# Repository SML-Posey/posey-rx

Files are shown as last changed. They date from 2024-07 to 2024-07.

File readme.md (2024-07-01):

# Posey Ring Platform

This is a simple IMU hardware platform sized to fit in a ring unit.

It includes:

- nRF52832 ARM microtroller with BLE radio
- CEVA BNO086 9-axis IMU
- Lithium-polymer operation and charging

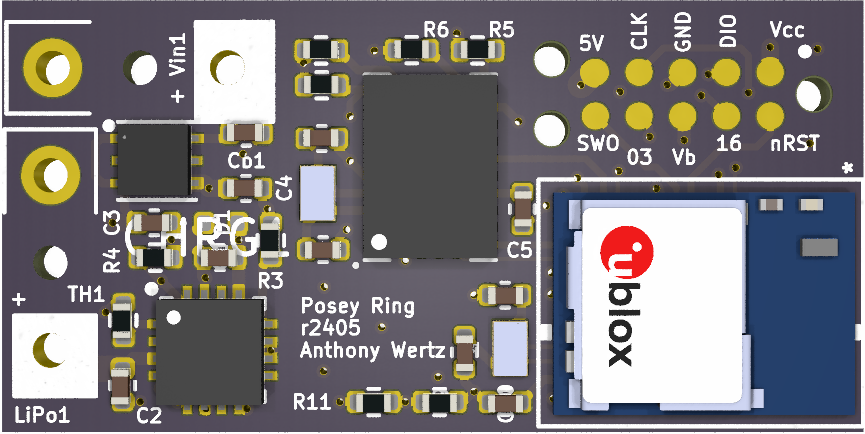
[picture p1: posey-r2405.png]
CAD rendering


## Author

[Anthony Wertz](https://me.anthonywertz.com)

## License

Shield: [][cc-by-sa]

This work is licensed under a
[Creative Commons Attribution-ShareAlike 4.0 International License][cc-by-sa].

[][cc-by-sa]

[cc-by-sa]: http://creativecommons.org/licenses/by-sa/4.0/
[cc-by-sa-image]: https://licensebuttons.net/l/by-sa/4.0/88x31.png
[cc-by-sa-shield]: https://img.shields.io/badge/License-CC%20BY--SA%204.0-lightgrey.svg

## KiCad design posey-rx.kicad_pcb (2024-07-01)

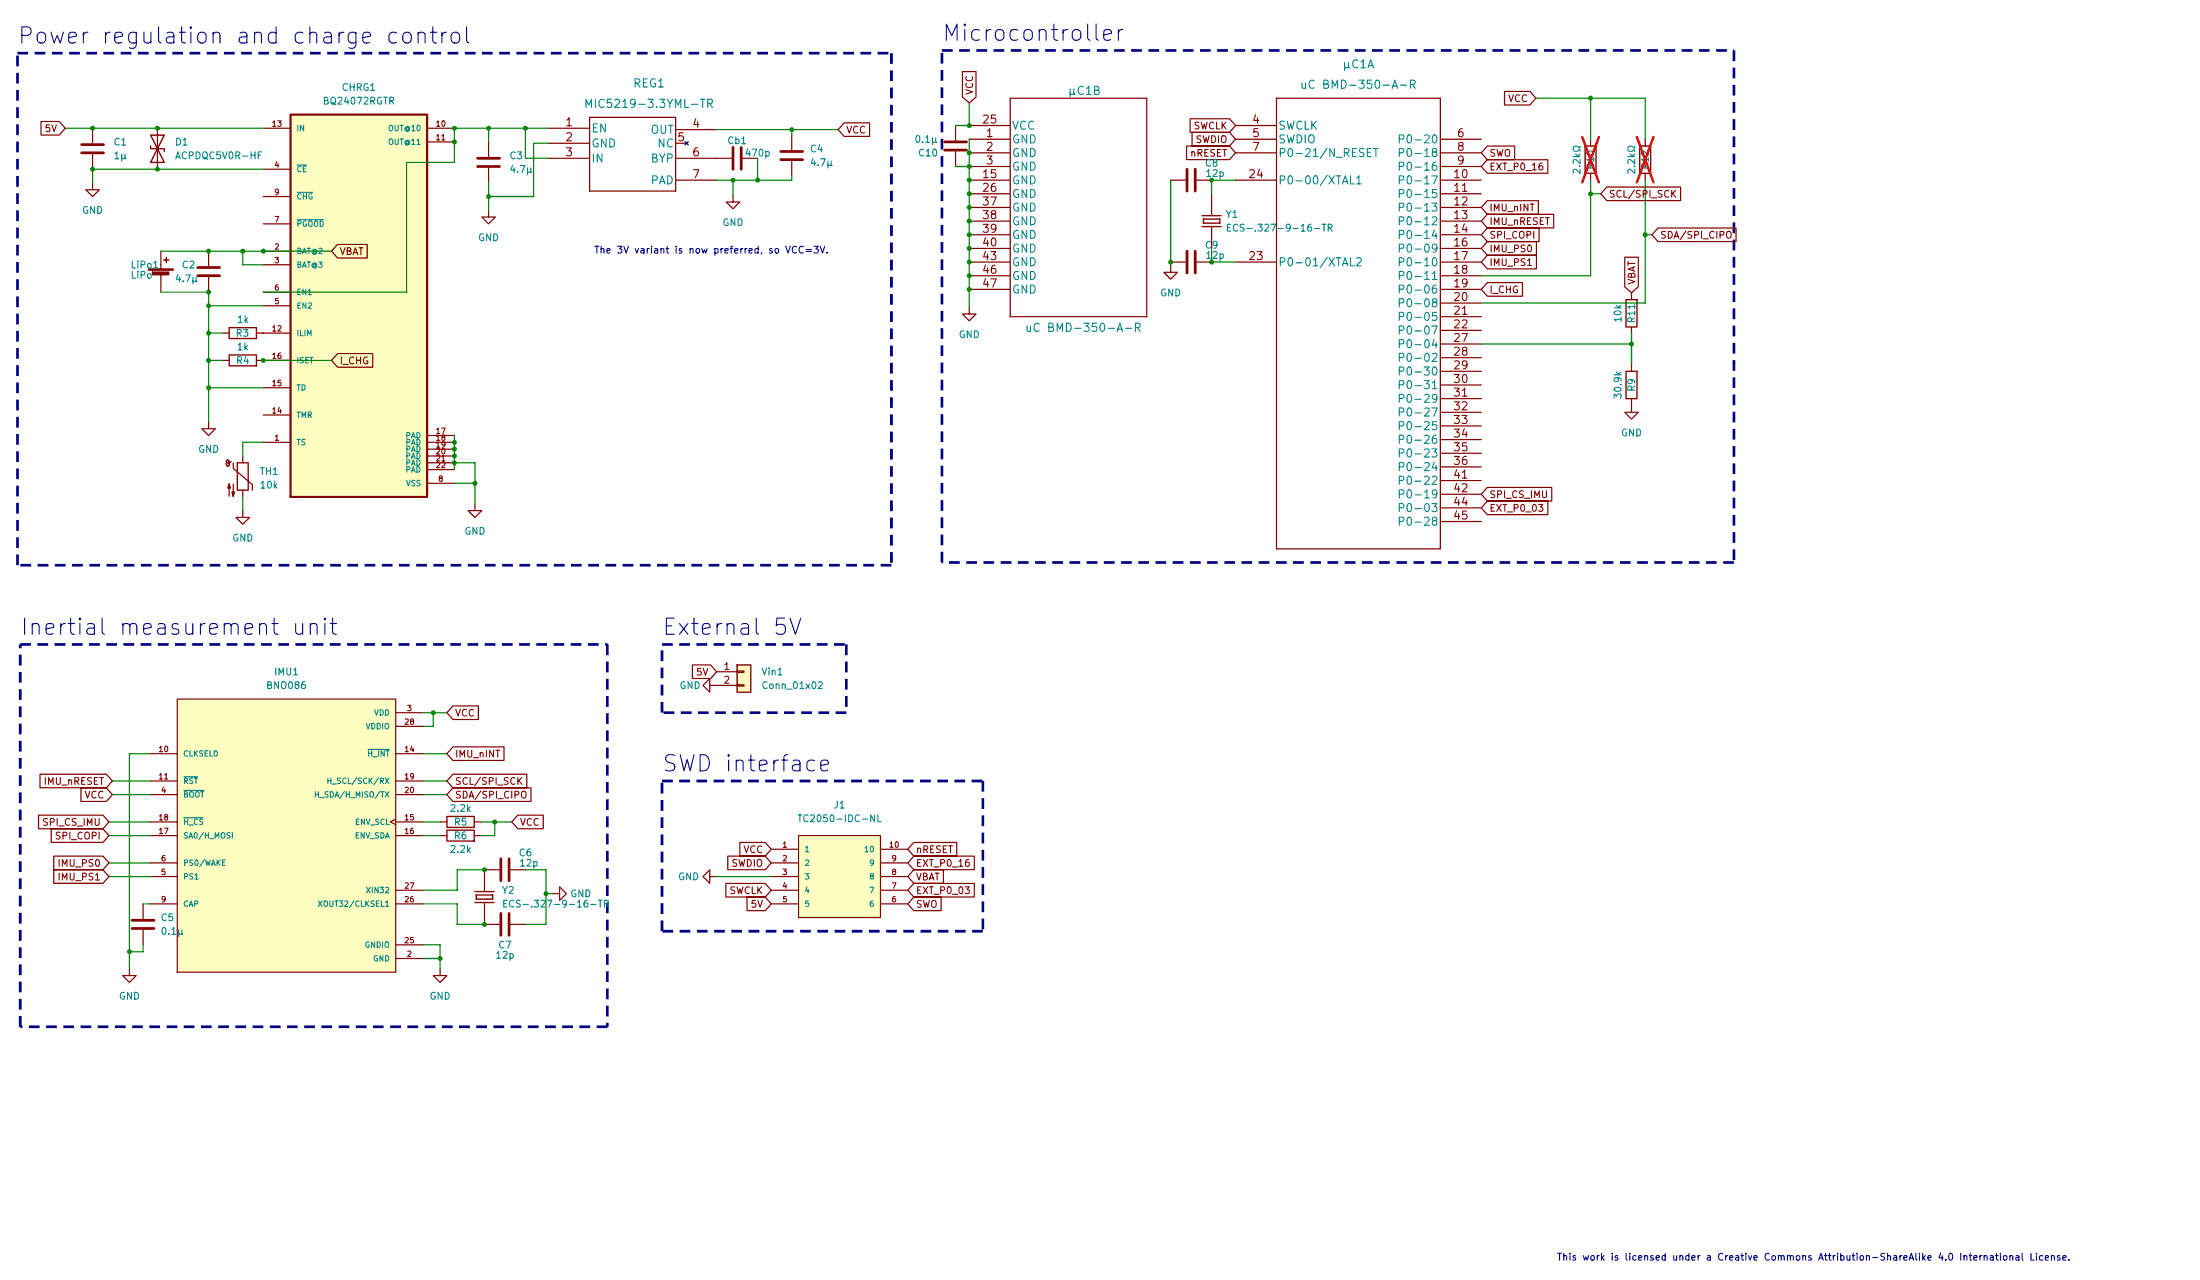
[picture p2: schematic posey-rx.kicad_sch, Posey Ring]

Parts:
C1: 1µ; C_0402_1005Metric
C2, C3, C4: 4.7µ; C_0402_1005Metric
C5, C10: 0.1µ; C_0402_1005Metric
C6, C7, C8, C9: 12p; C_0402_1005Metric
CHRG1: BQ24072RGTR; QFN50P300X300X100-17N
Cb1: 470p; C_0402_1005Metric
D1: ACPDQC5V0R-HF; D_0402_1005Metric
IMU1: BNO086; IC_BNO080
J1: TC2050-IDC-NL
LiPo1: LiPo; Split Terminal 2.54
R3, R4: 1k; R_0402_1005Metric
R5, R6: 2.2k; R_0402_1005Metric
R9: 30.9k; R_0402_1005Metric
R10, R12: 2.2kΩ; R_0402_1005Metric; not fitted
R11: 10k; R_0402_1005Metric
REG1: MIC5219-3.3YML-TR
TH1: 10k; R_0402_1005Metric
Vin1: Conn_01x02; Split Terminal 2.54
Y1, Y2: ECS-.327-9-16-TR; XTAL_ECS-.327-9-16-TR
µC1: uC BMD-350-A-R; BMD-350-A-R

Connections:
5V: C1.1, CHRG1.13 (IN), D1.2 (A2), J1.5, Vin1.1
EXT_P0_03: J1.7, µC1.44 (P0-03)
EXT_P0_16: J1.9, µC1.9 (P0-16)
GND: C1.2, C2.1, C3.2, C4.2, C5.2, C6.2, C7.2, C8.1, C9.1, C10.1, CHRG1.4 (~CE), CHRG1.5 (EN2), CHRG1.8 (VSS), CHRG1.15 (TD), CHRG1.17 (PAD), CHRG1.18 (PAD), CHRG1.19 (PAD), CHRG1.20 (PAD), CHRG1.21 (PAD), CHRG1.22 (PAD), Cb1.2, D1.1 (A1), IMU1.2 (GND), IMU1.10 (CLKSEL0), IMU1.25 (GNDIO), J1.3, LiPo1.2 (-), R3.1, R4.1, R9.1, REG1.2 (GND), REG1.7 (PAD), TH1.2, Vin1.2, µC1.1 (GND), µC1.2 (GND), µC1.3 (GND), µC1.15 (GND), µC1.26 (GND), µC1.37 (GND), µC1.38 (GND), µC1.39 (GND), µC1.40 (GND), µC1.43 (GND), µC1.46 (GND), µC1.47 (GND)
IMU_PS0: IMU1.6 (PS0/WAKE), µC1.16 (P0-09)
IMU_PS1: IMU1.5 (PS1), µC1.17 (P0-10)
IMU_nINT: IMU1.14 (~H_INT), µC1.12 (P0-13)
IMU_nRESET: IMU1.11 (~RST), µC1.13 (P0-12)
I_CHG: CHRG1.16 (ISET), R4.2, µC1.19 (P0-06)
unnamed: C3.1, CHRG1.6 (EN1), CHRG1.10 (OUT@10), CHRG1.11 (OUT@11), REG1.1 (EN), REG1.3 (IN)
unnamed: CHRG1.12 (ILIM), R3.2
unnamed: CHRG1.1 (TS), TH1.1
unnamed: C5.1, IMU1.9 (CAP)
unnamed: IMU1.15 (ENV_SCL), R5.1
unnamed: IMU1.16 (ENV_SDA), R6.1
unnamed: C6.1, IMU1.27 (XIN32), Y2.2
unnamed: C7.1, IMU1.26 (XOUT32/CLKSEL1), Y2.1
unnamed: Cb1.1, REG1.6 (BYP)
unnamed: C8.2, Y1.1, µC1.24 (P0-00/XTAL1)
unnamed: C9.2, Y1.2, µC1.23 (P0-01/XTAL2)
unnamed: R9.2, R11.1, µC1.27 (P0-04)
SCL/SPI_SCK: IMU1.19 (H_SCL/SCK/RX), R10.1, µC1.18 (P0-11)
SDA/SPI_CIPO: IMU1.20 (H_SDA/H_MISO/TX), R12.1, µC1.20 (P0-08)
SPI_COPI: IMU1.17 (SA0/H_MOSI), µC1.14 (P0-14)
SPI_CS_IMU: IMU1.18 (~H_CS), µC1.42 (P0-19)
SWCLK: J1.4, µC1.4 (SWCLK)
SWDIO: J1.2, µC1.5 (SWDIO)
SWO: J1.6, µC1.8 (P0-18)
VBAT: C2.2, CHRG1.2 (BAT@2), CHRG1.3 (BAT@3), J1.8, LiPo1.1 (+), R11.2
VCC: C4.1, C10.2, IMU1.3 (VDD), IMU1.4 (~BOOT), IMU1.28 (VDDIO), J1.1, R5.2, R6.2, R10.2, R12.2, REG1.4 (OUT), µC1.25 (VCC)
nRESET: J1.10, µC1.7 (P0-21/N_RESET)

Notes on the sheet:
Power regulation and charge control
Microcontroller
External 5V
The 3V variant is now preferred, so VCC=3V.
Inertial measurement unit
This work is licensed under a Creative Commons Attribution-ShareAlike 4.0 International License.
SWD interface

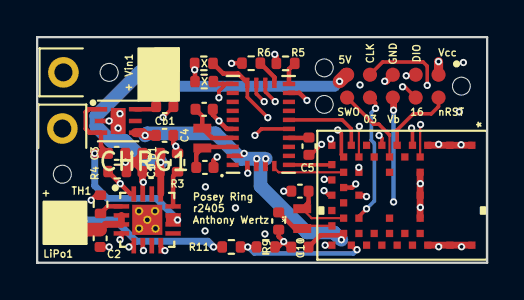
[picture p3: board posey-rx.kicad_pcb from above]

Board: 6 copper layers, 25.0 x 12.5 mm, 30 parts (0 on the bottom side), 31 nets.
